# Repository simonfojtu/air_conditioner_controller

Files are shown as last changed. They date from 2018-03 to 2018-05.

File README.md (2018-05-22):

# Air conditioner controller

Controller for an air conditioner unit

manufacturer: ACOND
models: AS-12UR4SYDDA, AS-09UR4SYDDA

## IR receiver and display module

connected to main unit via 5 wires:
- YK (orange)
- KEY (yellow)
- SDA1 (greenish)
- +5V (blue)
- GND (purple)

JST-SM 2.5mm connector, male connector view from the key side, cables going up: leftmost = gnd

- YK and KEY seems to be high (5V) all the time, except for some noise spikes
- SDA1 carries a signal, repeating slightly faster than 1Hz, presumably bidirectional, since the front unit needs to know the current temperature.single pulse is 5/6ms. i.e. 1.2kHz

=================
## ESP 8266 troubleshooting

http://www.esp8266.com/viewtopic.php?p=24592

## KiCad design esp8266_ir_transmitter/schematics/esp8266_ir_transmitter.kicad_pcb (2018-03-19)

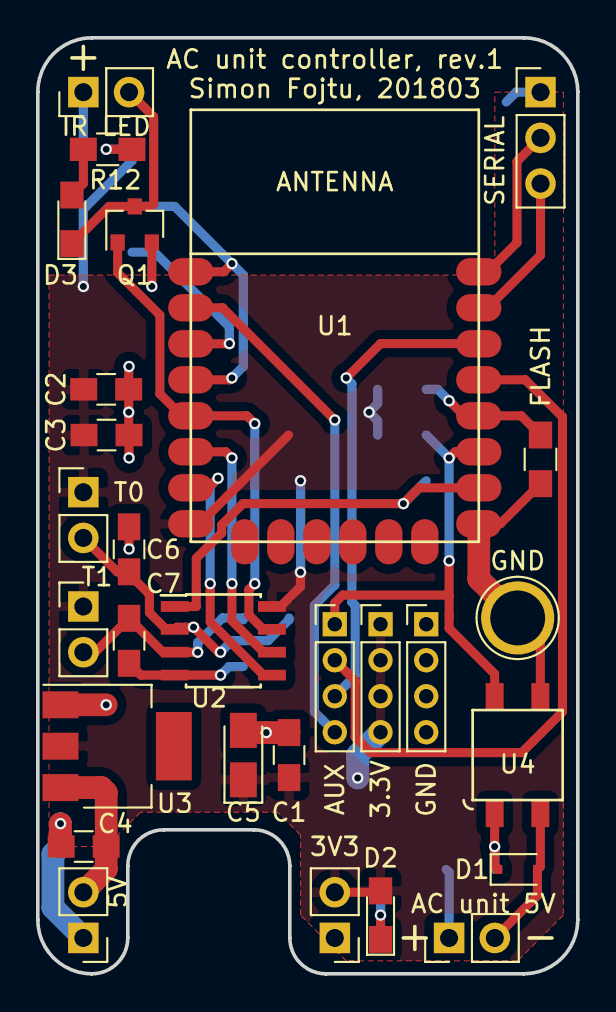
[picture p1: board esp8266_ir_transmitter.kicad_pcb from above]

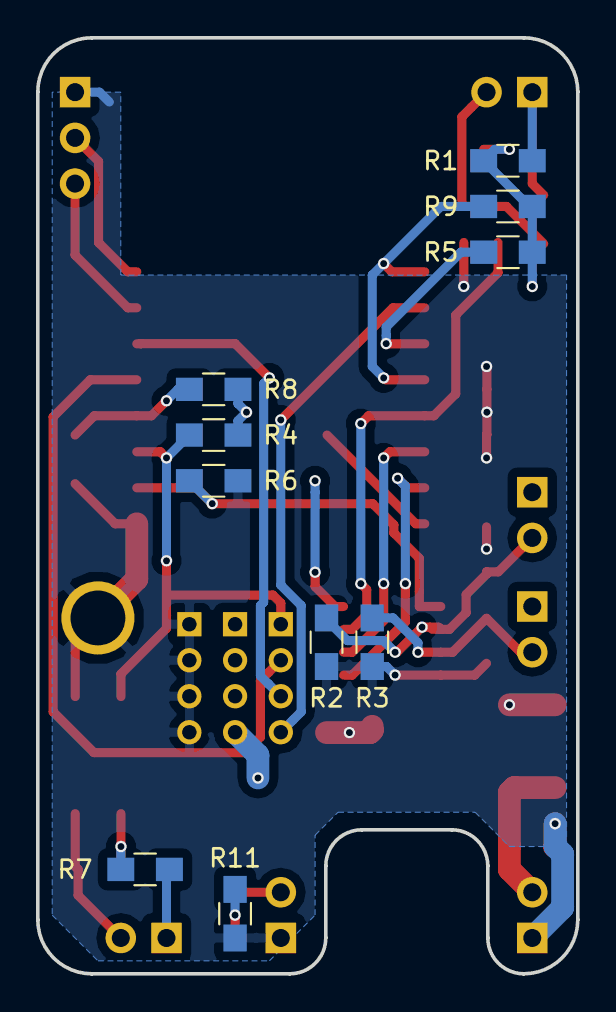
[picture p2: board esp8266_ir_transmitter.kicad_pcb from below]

Board: 2 copper layers, 30.0 x 52.0 mm, 38 parts (10 on the bottom side), 25 nets.

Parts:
C1, C3, C6, C7: 100n; C_0805_HandSoldering
C2: 10n; C_0805_HandSoldering
C4: 1uF, cer.; C_0805_HandSoldering
C5: 10uF, tant.; CP_Tantalum_Case-A_EIA-3216-18_Reflow
D1: BAS16J.115; D_SOD-323F
D2: power; LED_0805_HandSoldering
D3: LED; LED_0805_HandSoldering
P1: SERIAL; Pin_Header_Straight_1x03_Pitch2.54mm
P2: IR LED; Pin_Header_Straight_1x02_Pitch2.54mm
P3: 5V; Pin_Header_Straight_1x02_Pitch2.54mm
P4: 3V3; Pin_Header_Straight_1x02_Pitch2.54mm
P7: T0; Pin_Header_Straight_1x02_Pitch2.54mm
P10: T1; Pin_Header_Straight_1x02_Pitch2.54mm
P11: GND; 1pin
P12: AUX; Pin_Header_Straight_1x04_Pitch2.00mm
P13: GND; Pin_Header_Straight_1x04_Pitch2.00mm
P14: 3.3V; Pin_Header_Straight_1x04_Pitch2.00mm
P15: AC unit 5V; Pin_Header_Straight_1x02_Pitch2.54mm
Q1: 2N7002; SOT-23
R1, R6, R11, R12: 1k; R_0805_HandSoldering
R2, R3, R4, R7: R; R_0805_HandSoldering
R5, R8: 4k7; R_0805_HandSoldering
R9: 10k; R_0805_HandSoldering
R10: FLASH; R_0805_HandSoldering
U1: ESP-12-Q; esp8266-12-q
U2: MCP3002; SOIC-8_3.9x4.9mm_Pitch1.27mm
U3: LD1117S33TR; SOT-223
U4: LTV-356T

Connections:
+3V3: C1.1, C2.1, C3.1, C5.1, D2.2, P4.2, P7.1, P10.1, P14.1, P14.2, P14.3, P14.4, R1.1, R4.1, R5.1, R8.1, R9.2, R12.1, U1.8, U2.8, U3.2
+5V: C4.1, P3.2, U3.3
/ADC: P12.4, U1.2
/EN: R5.2, U1.3
/GPIO0: R8.2, R10.1, U1.18
/GPIO2: P12.1, R4.2, U1.17, U4.4
/GPIO4: P12.2, U1.19
/GPIO5: P12.3, U1.20
/GPIO12: U1.6, U2.6
/GPIO13: U1.7, U2.5
/GPIO14: Q1.1, U1.5, U2.7
/GPIO15: R6.2, U1.16, U2.1
/GPIO16: R9.1, U1.1, U1.4
/RX: P1.3, U1.21
/TX: P1.2, U1.22
GND: C1.2, C2.2, C3.2, C4.2, C5.2, C6.2, C7.2, P1.1, P3.1, P4.1, P11.1, P13.1, P13.2, P13.3, P13.4, Q1.2, R2.2, R3.2, R6.1, R10.2, R11.2, U1.15, U2.4, U3.1, U4.3
unnamed: C6.1, P7.2, R2.1, U2.2
unnamed: C7.1, P10.2, R3.1, U2.3
unnamed: D1.1, R7.2, U4.1
unnamed: D1.2, P15.2, U4.2
unnamed: D2.1, R11.1
unnamed: D3.1, P2.2, Q1.3
unnamed: D3.2, R12.2
unnamed: P2.1, R1.2
unnamed: P15.1, R7.1

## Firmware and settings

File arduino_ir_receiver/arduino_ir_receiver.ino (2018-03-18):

/* RGB Remote Control
   by: Jim Lindblom
   SparkFun Electronics
   date: October 1, 2013

   This sketch uses Ken Shirriff's *awesome* IRremote library:
       https://github.com/shirriff/Arduino-IRremote

   RGB Remote Control uses a combination of SparkFun's 
   IR Remote (https://www.sparkfun.com/products/11759) and an
   IR receiver diode (https://www.sparkfun.com/products/10266) to
   control an RGB LED.

   The IR Remote's power button turns the LED on or off. The A, B, 
   and C buttons select a channel (red, green, or blue). The up
   and down arrows increment or decrement the LED brightness on that channel.
   The left and right arrows turn a channel to min or max, and
   circle set it to the middle.

   Hardware setup:
     * The output of an IR Receiver Diode (38 kHz demodulating
       version) should be connected to the Arduino's pin 11.
       * The IR Receiver diode should also be powered off the
         Arduino's 5V and GND rails.
 */

#include <IRremote.h> // Include the IRremote library
#include <IRremoteInt.h>

/* Connect the output of the IR receiver diode. */
int RECV_PIN = 10;
/* Initialize the irrecv part of the IRremote  library */
IRrecv irrecv(RECV_PIN);
decode_results results; // This will store our IR received codes

void setup()
{
  Serial.begin(9600); // Use serial to debug.
  Serial.println("#start");
  irrecv.enableIRIn(); // Start the receiver
}

// loop() constantly checks for any received IR codes.
void loop()
{
  if (irrecv.decode(&results)) 
  {
    for (unsigned int i = 0; i < results.rawlen; i++) {
      Serial.print(results.rawbuf[i]);
      Serial.print(':');
    }
    Serial.println();
    irrecv.resume();
  }
}

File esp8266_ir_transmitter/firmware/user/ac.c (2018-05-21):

#include <esp8266.h>
#include <math.h>
#include "ac.h"
#include "driver/spi.h"
#include "ir.h"


static ACStatus status;
static ETSTimer updateTimer;

bool isPowered();

/**
 * Convert the AC settings to a binary representation
 */
uint8_t acEncode(const ACSettings settings, uint8_t * message, uint8_t length) {
    if (length < 12 * 4) {
    	os_printf("AC: FIXME: acEncode: message buffer too short (%d), expected at least 48.\n", length);
        return -1;
    }

    //                   <-           HEADER             ->
    uint8_t header[] = {1,1,0,0, 0,0,0,1, 0,1,1,0, 0,0,0,0};
    memcpy(message, header, 16);

    message[18] = settings.onOff ? 1 : 0;
    message[19] = settings.sleep ? 1 : 0;
    // fan
    switch (settings.fan) {
        case (AUTO):
            message[16] = 0;
            message[17] = 0;
            break;
        case (MAX):
            message[16] = 1;
            message[17] = 0;
            break;
        case (MED):
            message[16] = 0;
            message[17] = 1;
            break;
        case (MIN):
            message[16] = 1;
            message[17] = 1;
            break;
    }
    // mode
    switch (settings.mode) {
        case (SUN):
            message[24] = 0;
            message[25] = 0;
            message[26] = 0;
            break;
        case (FAN):
            message[24] = 0;
            message[25] = 0;
            message[26] = 1;
            break;
        case (COOL):
            message[24] = 0;
            message[25] = 1;
            message[26] = 0;
            break;
        case (SMART):
            message[24] = 1;
            message[25] = 0;
            message[26] = 0;
            break;
        case (DROPS):
            message[24] = 1;
            message[25] = 1;
            message[26] = 0;
            break;
    }
    // temperature
    {
        uint8_t t = settings.temp - 16;
        message[28] = t & 0x1;
        message[29] = (t & 0x2) >> 1;
        message[30] = (t & 0x4) >> 2;
        message[31] = (t & 0x8) >> 3;
    }

    return 0;
}

/**
 * Convert the binary representation of the settings to the IR pulses lengths
 */
void irEncode(uint8_t* message, uint8_t message_length, uint16_t* encoded) {
    // encoded length is 2 * message_length + 3
    static const uint16_t SHORT = 11*50;
    static const uint16_t LONG = 32*50;
    // hardcoded header
    encoded[0] = 180*50;
    encoded[1] = 90*50;

    int index = 2;
    for (int i = 0; i < message_length; i++) {
        encoded[index++] = SHORT;
        encoded[index++] = (message[i] == 1 ? LONG : SHORT);
    }
    // Append a SHORT pulse at the end, as recorded
    encoded[index] = SHORT;
}

/**
 * Send a command to the AC unit to power up
 */
void start(void) {
    if (!isPowered()) {
        status.settings.onOff = true;
        send(status.settings);
    }
}

/**
 * Send a command to the AC unit to power down
 */
void stop(void) {
    if (isPowered()) {
        status.settings.onOff = true;
        send(status.settings);
    }
}

void setTemperature(uint8_t temperature) {
    if (isPowered()) {
        status.settings.temp = temperature;
        send(status.settings);
    }
}


void setMode(ac_mode_t mode) {
    if (isPowered()) {
        status.settings.mode = mode;
        send(status.settings);
    }
}


void setFanSpeed(ac_fan_t fan) {
    if (isPowered()) {
        status.settings.fan = fan;
        send(status.settings);
    }
}


/**
 * Send a command to the AC unit to set the given parameters
 */
void send(ACSettings settings) {
    os_printf("AC: send\n");
    uint8_t encoded[48];
    uint16_t buffer[48*2+3];
    uint8_t ret = acEncode(settings, encoded, 48);
    if (ret != 0)
        return;

    status.settings = settings;
    irEncode(encoded, 48, buffer);
    processCommand(buffer, 48*2+3);

    // disable on/off and sleep toggle
    status.settings.onOff = false;
    status.settings.sleep = false;
}

/**
 * Get current status of the AC unit
 */
ACStatus get(void) {
    return status;
}


/**
 * Compute temperature in degrees C given NTC thermocouple parameters
 */
static float ICACHE_FLASH_ATTR ntc(int B, int R0, int R) {
    float rinf = R0 * exp(-B / (273.15 + 25));
    return B / log(R / rinf) - 273.15;
}


/**
 * Read temperature of a NTC thermistor via MCP3002
 *
 * @param channel - only value 0 or 1 is valid
 * @return measured temperature in degrees Celsius
 */
static float measureTemperature(uint8_t channel) {
    // value of R2 and R3 resistors
    // TODO allow for calibration
    static const int R2 = 10000; // channel0
    static const int R3 = 10000; // channel1
    // NTC R0 resistance value
    static const int NTC_R0 = 22000;
    // NTC B coefficient
    static const int NTC_B = 4150;
    // Power supply voltage
    static const float VCC = 3.3;

    // SPI command: start, sgl, channel0, msbf
    uint32_t adc = spi_transaction(HSPI, 4, 0b1101 | (1 << channel), 0, 0, 0, 0, 11, 0);
    os_printf("ADC value (ch %d): %d\n", channel, adc);
    float vout = adc * VCC / 1024;
    float temperature = ntc(NTC_B, NTC_R0, (VCC - vout) / vout * (channel == 0 ? R2 : R3));
    return temperature;
}

/**
 * Update status with current temperature
 */
void readTemperature(void) {
    // initialize SPI for communication with MCP3002
    // GPIO14 (SPI CLK) is reused for IR output, thus SPI needs to be reinitialized
    spi_init(HSPI);
    status.temperatureIn = measureTemperature(0);
    status.temperatureOut = measureTemperature(1);
    os_printf("AC: Temp in: %d, temp out: %d\n", (int) status.temperatureIn, (int) status.temperatureOut);
}

/**
 * Determine if the AC unit is powered up
 */
bool isPowered() {
    // TODO implement this
    os_printf("AC: isPowered: Not implemented yet\n");
    return true;
}


/**
 * Update temperature and power status
 */
void update(void *arg) {
    readTemperature();
    status.started = isPowered();
}

/**
 * Initialize subsystems and update timer
 */
void acInit(void) {
    // default values
    status.settings.temp = 21;
    status.settings.fan = AUTO;
    status.settings.mode = COOL;
    status.settings.onOff = false;
    status.settings.sleep = false;

    // initialize IR subsystem
    irInit();

    update(NULL);

    // set up repeating task to update temperature
    os_timer_disarm(&updateTimer);
    os_timer_setfn(&updateTimer, (os_timer_func_t *)update, NULL);
    os_timer_arm(&updateTimer, 10000, true);
}

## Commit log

2018-03-18 Arduino sketch to record IR commands from the original IR controller.
2018-03-18 PCB rev1
    [esp8266_ir_transmitter.kicad_pcb, esp8266_ir_transmitter.sch]
2018-03-19 PCB revision 1
    [esp8266_ir_transmitter.kicad_pcb, esp8266_ir_transmitter.sch]
2018-04-28 moving spi library
2018-04-29 Reading temperature via NTC and MCP3002 over SPI
2018-04-29 Reduced uart messages
2018-05-02 Note about front panel to guts cable connector pinout
2018-05-11 Fixed sending temperatures update without leading space
2018-05-11 Temperature read on AC init
2018-05-18 Fan and mode are adjustable via mqtt
2018-05-20 Openhab2 actually listens to state (setpoint, fan, mode, ..); reduced update rate to every 20s
2018-05-21 Updated comment about why SPI does not work after IR command is sent
    [ac.c]
2018-05-22 Fixups of esp8266 ir transmitter schematics for next revision
    [esp8266_ir_transmitter.sch]
